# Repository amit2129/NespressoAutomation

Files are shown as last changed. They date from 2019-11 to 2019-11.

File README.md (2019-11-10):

# NespressoAutomation
Automating Nespresso U-Series

The goal with this project is to automate the Nespresso U coffee machine
to work completely hands free, making espresso by voice command.

There are several different "components" in this project:

1. 3D design, meant for 3D printing, the main items are:  
    * A stack which contains the capsules - the current "best" design can hold 6 capusles and works great with 3rd party capsules.
    * A capsule "selector" arm which drops capsules one at a time
    * A capsule door opener which moves the capsule door back and forth 
    
2. Electronics:
    * An arduino uno - [link](http://www.aliexpress.com/item/32697443734.html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 "Arduino Uno With USB") ~ 3$
    * A stepper driver board - [link](https://www.aliexpress.com/item/32909152477.html?spm=a2g0o.productlist.0.0.59a67d0cHCASpA "L293D Motor Shield") ~ 1.25$
    * A CD ROM Stepper - can be removed from any old CD ROM Drive, one can be bought on aliexpress or ebay but IIRC it needs a travel of 50mm ~ 2$
    * A 28byj-48 "Modified to be bipolar" - [link](http://www.aliexpress.com/item/32896006818.html?spm=a2g0o.productlist.0.0.786b6e4eyxfZal "28byj-48") ~ 1.5$
    * A Sonoff Smart switch - [link](http://www.aliexpress.com/item/32877725098.html?spm=a2g0o.productlist.0.0.44432afdtdHAVP "Sonoff Smart Switch") ~ 4.5$
    
3. Software:
    * A short arduino 'script' making coffee and then doing nothing forever.
    I have plans to record the number of times coffee has been made and writing
    it to EEPROM but writing to the same location in EEPROM wears it out quickly
    so I'm trying to find a different elegant solution for easy read and write.

# Improvements - Suggestions are welcome
* I tried using a NodeMCU (wifi enabled) to trigger the arduino to make coffee so I could have MQTT (IFTTT Integration) but had trouble with the logic level shifting, it would work when it received the activation command but also when I just touched the USB port and sometimes randomly without any noted change in IFTTT so it was a connection issue with the arduino and the NodeMCU.

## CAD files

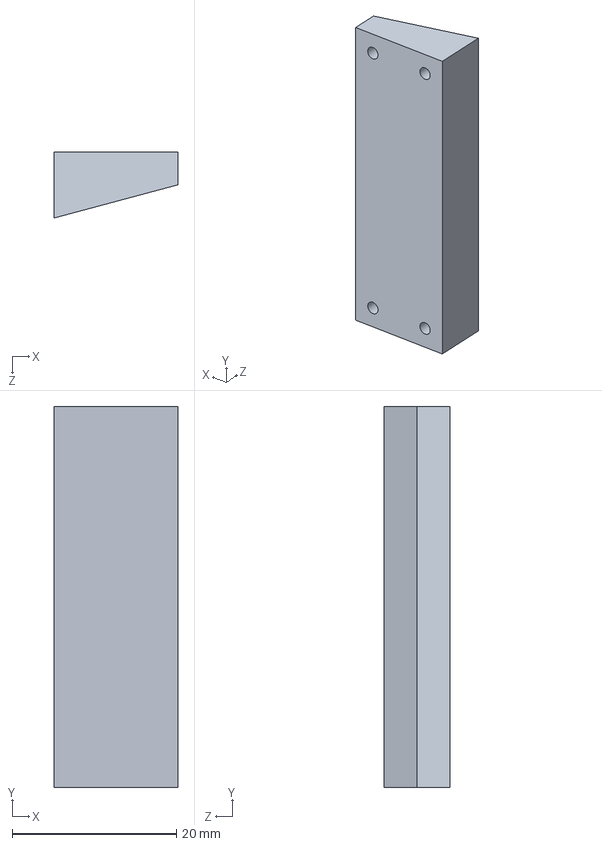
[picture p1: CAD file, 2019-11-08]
3D_files/SolidWorks files/CD ROM stepper angled mount.SLDPRT
15.1 x 46.4 x 8.05 mm

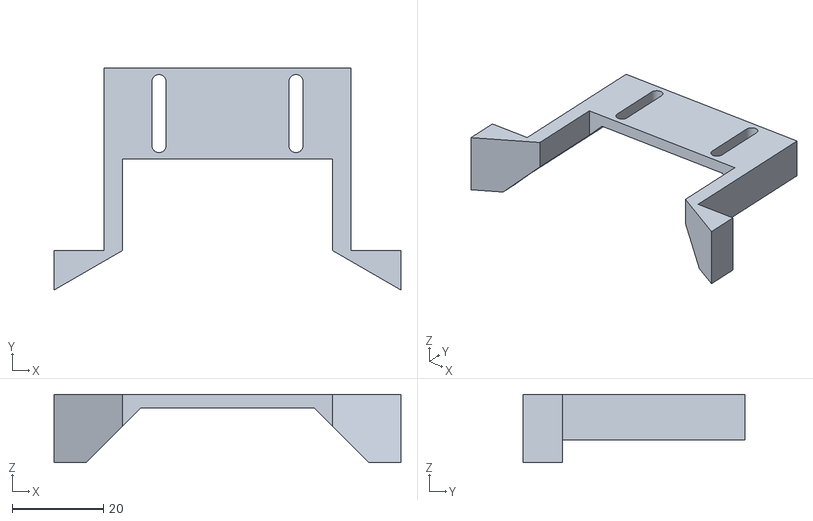
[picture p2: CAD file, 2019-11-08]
3D_files/STLs ready for printing/capsule stack back support.STL
76.0 x 48.7 x 15.0

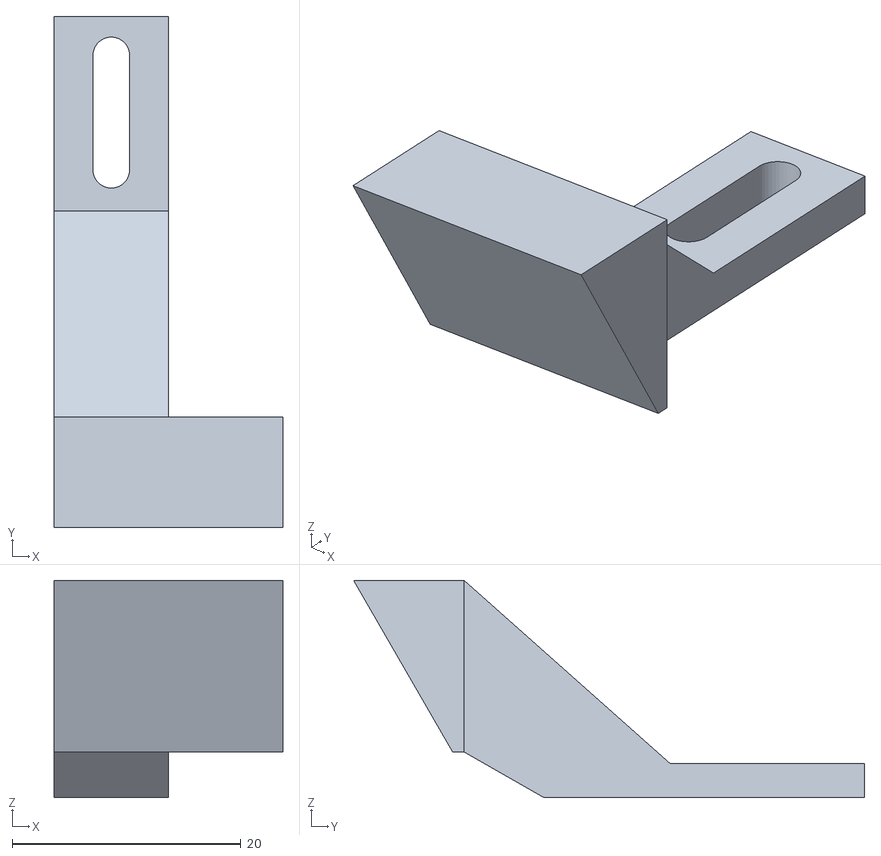
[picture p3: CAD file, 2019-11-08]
3D_files/STLs ready for printing/capsule stack holder front LEFT.stl
20.0 x 44.7 x 19.0

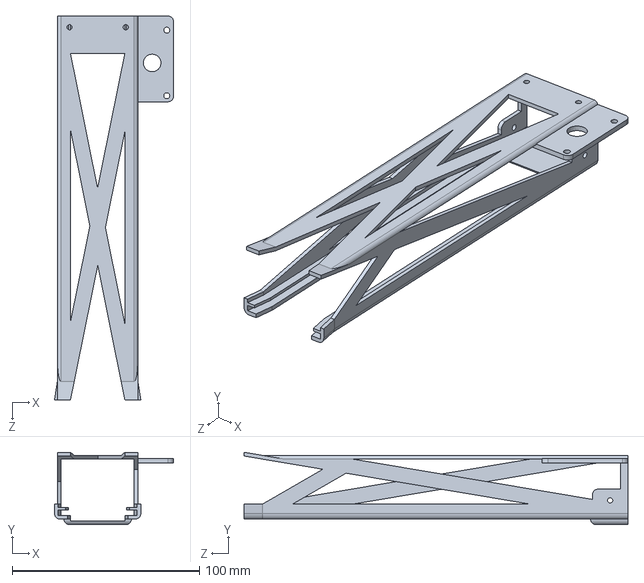
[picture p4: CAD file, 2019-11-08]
3D_files/SolidWorks files/capsule stack.SLDPRT
63.6 x 38.7 x 204.9 mm

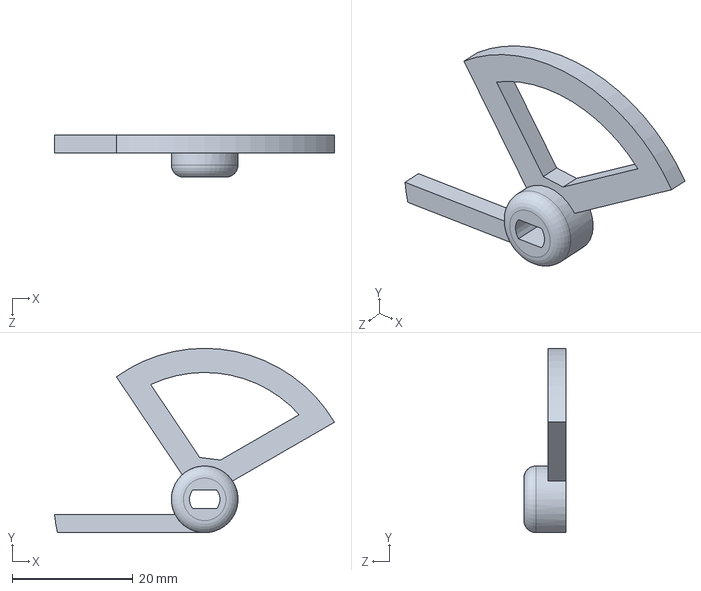
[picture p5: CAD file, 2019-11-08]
3D_files/SolidWorks files/modified selector.SLDPRT
46.4 x 30.5 x 7.00 mm

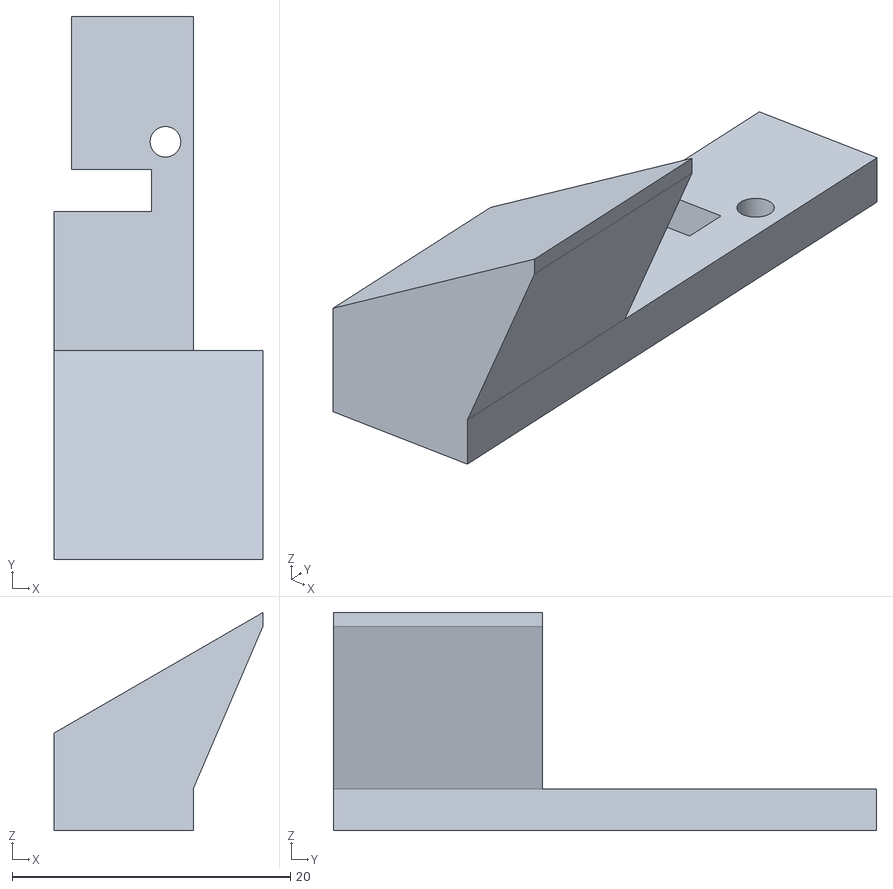
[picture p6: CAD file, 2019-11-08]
3D_files/STLs ready for printing/cd stepper carriage extension part used.STL
15.0 x 39.0 x 15.7

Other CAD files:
3D_files/SolidWorks files/capsule stack back support.SLDPRT
3D_files/STLs ready for printing/CD ROM stepper angled mount.STL
3D_files/SolidWorks files/capsule stack holder front.SLDPRT
3D_files/STLs ready for printing/capsule stack.STL
3D_files/SolidWorks files/stepper carriage extension.SLDPRT
3D_files/STLs ready for printing/capsule stack holder front RIGHT.STL
3D_files/STLs ready for printing/cd stepper carriage extension modified.STL

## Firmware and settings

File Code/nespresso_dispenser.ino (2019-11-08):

/*
 * Author: Amit Matityahu
 * Nespresso Coffee Machine Automator
 * This relatively short piece of code 
 * is made to run once (the arduino is powered on
 * performs the task and is powered off once it is done)
 * additionally there's a counter which is writen to eeprom
 * counting the number of times the machine has been activated
 * (made coffee)
*/
#include <AFMotor.h>
#include <EEPROM.h>

struct Statistics{
  int coffeeMade;
};



int eeAddress = 0;   //Location we want the data to be put.


int CAPSULE_REV = 4076/2;
int DOOR_REV = 20;
double door_calibration = 460;


AF_Stepper doorStepper(20, 2);
AF_Stepper capsuleStepper(48, 1);
byte curr_low;
byte curr_high;
int res;
const int addr = 0;
const byte BITS_PER_BYTE = 8;
const int make_coffee = 2;
volatile bool doAction = false;



void makeCoffee();

int data;

Statistics stats = {
  0  
};
void setup() {

  pinMode(make_coffee, INPUT);
  //attachInterrupt(digitalPinToInterrupt(make_coffee), make_coffee_handler, FALLING);
  Serial.begin(9600);
  //setting speed for both motors
  capsuleStepper.setSpeed(400);
  doorStepper.setSpeed(1300);
  capsuleStepper.release();
  doorStepper.release();
  makeCoffee();


 
  EEPROM.put(eeAddress, stats);
  
}

void loop() {
//  doAction = !digitalRead(make_coffee);
//  Serial.println(doAction);
//  Serial.print(" ");
//  if (doAction){
//    makeCoffee();
//    doAction = false;
//  }
}

void makeCoffee(){
  //Serial.println("making coffee");
  doorStepper.step(door_calibration,
  FORWARD, INTERLEAVE);
  capsuleStepper.step(CAPSULE_REV/6, FORWARD, DOUBLE);
  doorStepper.step(door_calibration, BACKWARD, INTERLEAVE);
  capsuleStepper.step(CAPSULE_REV/7 + 20, BACKWARD, DOUBLE);
  capsuleStepper.release();
  doorStepper.release();
  delay(5000);
  stats.coffeeMade++;
  EEPROM.put(eeAddress,stats);
  
}

void make_coffee_handler(){
  doAction = true;
}

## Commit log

2019-11-08 [Feature] Initial Commit
    The initial commit containing all the files up to this point
    [CD ROM stepper angled mount.SLDPRT, CD ROM stepper angled mount.STL, capsule stack back support.SLDPRT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]
2019-11-08 [Bug] change folder name 3D Files -> 3D_files
    [CD ROM stepper angled mount.SLDPRT, CD ROM stepper angled mount.STL, capsule stack back support.SLDPRT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]
